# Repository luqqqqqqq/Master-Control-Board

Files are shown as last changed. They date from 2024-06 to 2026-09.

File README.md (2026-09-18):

# Master Control Board v1.0.0

<div align="center">

**面向机器人控制系统的开源 STM32 主控板**<br>
*An open-source STM32 control board for robotics projects*



[快速开始](#快速开始) · [文档导航](#文档导航) · [更新日志](CHANGELOG.md)

</div>

<p align="center">
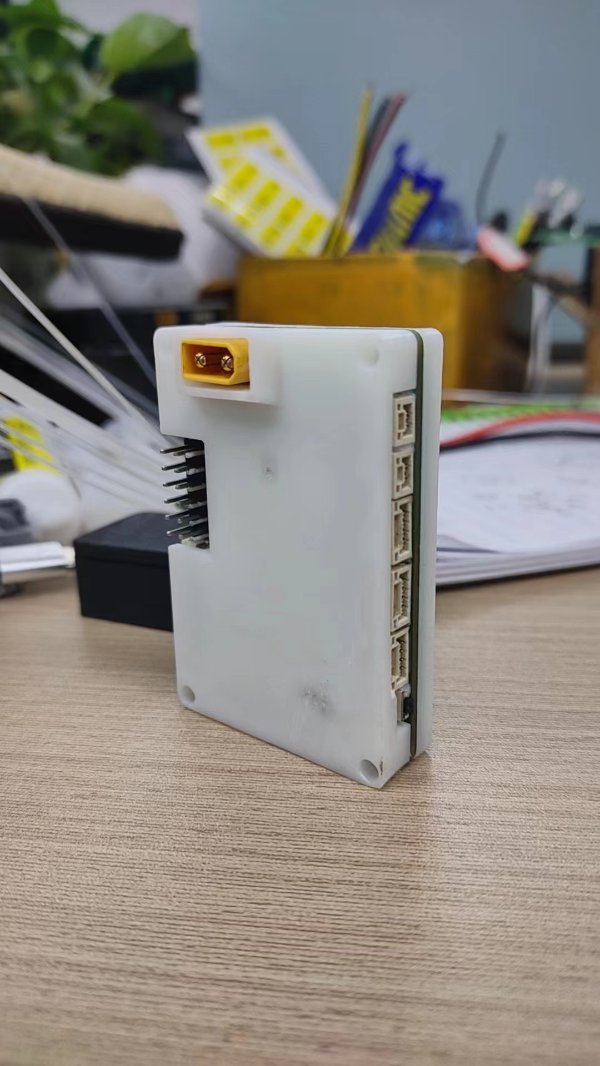
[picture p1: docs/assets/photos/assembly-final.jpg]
Assembled Master Control Board
  
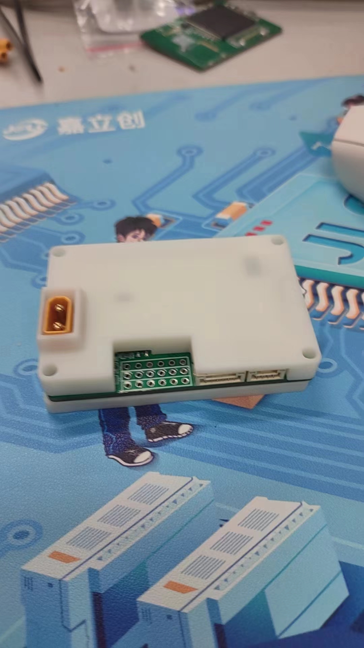
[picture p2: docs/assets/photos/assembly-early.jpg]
Early assembly
  
</p>

## 项目简介

Master Control Board 是一块以 **STM32F407VET6** 为核心、集成 **BMI270 六轴 IMU** 的机器人主控板，定位类似 DJI C Board 的通用控制核心。项目已在 RM 比赛项目中实际使用。本仓库提供 `v1.0.0` 的 PCB、固件、外壳和制造资料。

Master Control Board `v1.0.0` includes hardware design files, firmware, enclosure models and manufacturing files. The board has been used in RM competition projects; formal electrical and environmental test reports are still incomplete.

## 主要特性

| 功能 | 说明 |
| --- | --- |
| MCU | STM32F407VET6，LQFP100，Cortex-M4F |
| IMU | Bosch BMI270，SPI2 接口 |
| 实时系统 | FreeRTOS / CMSIS-RTOS v1 |
| 总线 | CAN1、CAN2（当前 CubeMX 配置为 1 Mbps） |
| 串行接口 | USART1/2/3/6、UART4/5 |
| 其他外设 | SPI1、SPI2、IWDG、RGB 指示灯、激光/外部中断接口 |

## 快速开始

1. 安装 STM32CubeMX、Keil MDK-ARM 和对应的 STM32F4 Device Pack。
2. 用 Keil 打开 [Luq Board.uvprojx](src/firmware/MDK-ARM/Luq%20Board.uvprojx)，选择 `Luq Board` target 后编译。
3. 使用 ST-Link 或 J-Link 烧录生成的固件；仓库也保留了 [v1.0.0 固件镜像](releases/v1.0.0/Luq_Board_v1.0.0.hex)。
4. 制作硬件时，从 [PCB 工程](hardware/pcb/luq_board.eprj) 和 [制造资料](hardware/pcb/manufacturing/) 开始。

完整的环境、编译、烧录与制造入口见 [快速开始](docs/getting-started.md)。制作前请结合板厂能力核对叠层、阻抗和器件封装。

## 目录结构

```text
.
├── src/
│   └── firmware/              # CubeMX、Keil、应用源码与第三方驱动
├── hardware/
│   ├── pcb/                   # PCB 工程、Gerber、BOM 与贴片坐标
│   ├── mechanical/            # 外壳与 3D CAD 文件
│   └── datasheets/            # 芯片参考资料
├── releases/
│   └── v1.0.0/                # 随项目保存的固件镜像
├── tools/
│   └── stm-studio/            # IMU 观察配置
├── docs/
│   ├── README.md              # 文档导航
│   ├── getting-started.md     # 编译、烧录与制造入口
│   ├── development.md         # 外设、工程约定与验证范围
│   ├── firmware-layout.md     # 固件源码与工程入口
│   ├── hardware/              # 制造、装配与 IMU 设计说明
│   └── assets/photos/         # 装配照片
├── README.md
├── CHANGELOG.md
├── VERSION
├── .gitignore
└── LICENSE
```

Keil 中间文件留在工具默认输出目录并由 Git 忽略；`releases/` 只保存明确提供的固件镜像。

## 文档导航

| 文档 | 内容 |
| --- | --- |
| [文档索引](docs/README.md) | 固件、硬件和发布文件的阅读入口 |
| [快速开始](docs/getting-started.md) | 开发环境、编译、烧录与制作硬件 |
| [开发与验证](docs/development.md) | 外设配置、工程约定、STM Studio 与验证范围 |
| [固件目录说明](docs/firmware-layout.md) | CubeMX、Keil 和各源码目录的职责 |
| [制造资料说明](docs/hardware/manufacturing.md) | BOM、贴片坐标与制板前检查 |
| [装配注意事项](docs/hardware/assembly-notes.md) | 外壳、焊点、导热与机械固定 |
| [IMU 设计记录](docs/hardware/imu-layout-notes.md) | 机械应力、温漂和验证建议 |
| [更新日志](CHANGELOG.md) | 版本内容与变更记录 |

## 开发与验证

构建入口为 [Keil 工程](src/firmware/MDK-ARM/Luq%20Board.uvprojx)，配置入口为 [CubeMX 工程](src/firmware/Luq%20Board.ioc)。更完整的维护说明见 [开发与验证](docs/development.md)。

- 已核对工程源文件、包含目录、文档与工具相对引用；目录整理保持固件源码、硬件资产和固件镜像内容不变。
- 本次检查不包含固件编译、烧录或真机测试。
- 项目已在 RM 比赛项目中投入使用；温漂、振动、长期稳定性和完整电气参数测试尚未形成正式报告。
- 目标芯片以 STM32F407VET6 工程配置为准。

## 致谢

感谢 **SZU PR 战队** 提供设备支持和测试条件。

本仓库的 README、文档与目录结构采用作者的 `github-repo-template` 统一模板，通过 Codex 技能维护。

## 许可证

项目顶层采用 [GNU GPL-3.0](LICENSE)。STM32 HAL、CMSIS、FreeRTOS 和 BMI270 API 等第三方代码保留其原始许可证与版权声明；分发时请一并遵守对应目录中的许可文件。

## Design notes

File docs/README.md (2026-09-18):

# 文档导航

[返回项目首页](../README.md)

| 文档 | 内容 |
| --- | --- |
| [快速开始](getting-started.md) | 开发环境、编译、烧录与硬件制作入口 |
| [开发与验证](development.md) | 外设配置、代码约定、STM Studio 与验证范围 |
| [固件目录说明](firmware-layout.md) | CubeMX、Keil 与各源码目录的职责 |
| [制造资料说明](hardware/manufacturing.md) | 制造文件及下单前检查 |
| [装配注意事项](hardware/assembly-notes.md) | 外壳、导热、焊点与机械固定 |
| [IMU 设计记录](hardware/imu-layout-notes.md) | 应力、温漂与验证建议 |
| [固件镜像](../releases/v1.0.0/README.md) | 随项目保存的 v1.0.0 HEX 文件 |
| [更新日志](../CHANGELOG.md) | 版本内容与变更记录 |

初次使用从“快速开始”阅读；修改固件前阅读“开发与验证”，制作硬件前核对制造与装配说明。芯片参考资料见 [hardware/datasheets](../hardware/datasheets/)。

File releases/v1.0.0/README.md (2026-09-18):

# Master Control Board v1.0.0 固件

[返回项目首页](../../README.md) · [快速开始](../../docs/getting-started.md)

本目录保留随项目提供的 [Luq_Board_v1.0.0.hex](Luq_Board_v1.0.0.hex)。目录整理未重新编译或修改该镜像。

目标工程为 STM32F407VET6。烧录前确认实际板卡、连接方式和固件需求；修改源码后请从 [Keil 工程](../../src/firmware/MDK-ARM/Luq%20Board.uvprojx) 重新构建，再验证生成的固件。

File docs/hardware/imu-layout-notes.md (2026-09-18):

# BMI270 区域设计记录

BMI270 的零偏和温漂会受到 PCB 应变、外部振动和温度梯度影响。本文件记录当前版本的设计取舍，属于工程笔记，不能替代实测数据。

## 机械应力

- 在陀螺仪周围保留足够的开槽和净空，减少板弯和外壳装配力传递到器件。
- 外壳固定可以提高整体抗冲击能力，但螺丝和卡扣不能直接给 PCB 施加过大预紧力。
- PCB 加厚能提高刚性，同时会增加重量、成本和热阻，应通过振动与温漂测试决定是否采用。

## 热设计

- 可使用柔性导热垫或低应力固化导热材料帮助均温，但必须控制厚度和固化收缩。
- 导热材料不应挤压 BMI270，也不应遮挡需要保持开口的结构区域。
- 热路径应连接到连续铜区或外壳散热结构；单纯增加材料厚度不能替代温度测试。

## 验证建议

装配完成后，建议分别记录静置、升温、风扇扰动和振动条件下的零偏变化，并把测试结果与机械方案、导热材料批次一起归档。

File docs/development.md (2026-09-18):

# 开发与验证

[返回项目首页](../README.md) · [文档导航](README.md)

本文记录 `v1.0.0` 固件的 CubeMX/Keil 配置要点。工程目标以 `Luq Board.ioc` 和 Keil 工程中的 `STM32F407VETx` 配置为准；下文源码路径均相对于 [`src/firmware/`](../src/firmware/)。

## 快速构建

1. 使用 STM32CubeMX 打开 `Luq Board.ioc`，芯片选择 STM32F407VET6、LQFP100。
2. 使用 Keil MDK-ARM 打开 `MDK-ARM/Luq Board.uvprojx`。
3. 安装对应版本的 STM32F4xx Device Pack，选择 `Luq Board` target 后编译。
4. 使用 ST-Link 或 J-Link 烧录生成的 `.hex` 文件。

## 外设概览

- **CAN1、CAN2**：CubeMX 当前配置为 1 Mbps，启用自动离线管理和自动唤醒。
- **USART1/2/3、UART4/5、USART6**：串口接收使用 DMA/中断组合，具体引脚以 `.ioc` 为准。
- **SPI1、SPI2**：SPI2 连接 BMI270，片选由 GPIO 控制。
- **FreeRTOS**：任务入口在 `Task/Src/user_task.c`，回调集中在 `Task/Src/user_handler.c`。
- **IWDG**：用于基础运行时看门狗保护。

## 工程约定

- `Core/` 保存 CubeMX 生成的初始化、中断和 HAL glue code。
- `Peripherals/` 提供 CAN、UART、SPI、TIM、GPIO 等项目驱动封装。
- `BMI270/` 保留 Bosch BMI270 Sensor API 及其适配代码。
- 重生成 CubeMX 工程时，保留用户代码区，并检查 Keil 工程中的 include path 和 source group。
- 任务逻辑优先放入 `Task/`，设备初始化放在 `Peripherals/Src/dev_drv.c`，对应头文件位于 `Peripherals/Inc/dev_drv.h`。

## 关键配置

### 时钟与系统

- 使用外部高速晶振，系统时钟按 STM32F407VET6 的最高允许频率配置。
- HAL 时基使用 TIM2，FreeRTOS 使用 SysTick。
- 开启 FPU、IWDG 和 CMSIS-RTOS v1；FreeRTOS 堆大小在 CubeMX 工程中设置。

### 接口分配

最终引脚、DMA stream、NVIC 优先级和 CAN 时序均以 `Luq Board.ioc` 为准。修改 CubeMX 配置后，需要重新检查 Keil 工程的用户文件分组和 include path。

### 项目驱动

- `uart_drv.*`：串口 DMA/空闲线接收封装。
- `can_drv.*`：CAN 收发和接收回调封装。
- `tim_drv.*`：定时器功能扩展点。
- `gpio_drv.*`：LED、激光和外部中断相关 GPIO 宏与操作。
- `bmi_drv.*`：BMI270 初始化和数据读取适配。

## STM Studio 观察 IMU

使用 STM Studio 打开 [st-studio-imu.tsp](../tools/stm-studio/st-studio-imu.tsp)，它引用同目录的 [st-studio-imu.tsc](../tools/stm-studio/st-studio-imu.tsc)。配置指向本地编译生成的 `src/firmware/MDK-ARM/Luq Board/Luq Board.axf`，用于查看 `test.acc_*`、`test.gyr_*` 和 `test.temp`。

使用前先编译对应固件，并在 STM Studio 中确认或重新导入当前 AXF 的变量地址；配置中保存的历史地址不能代替当前构建的符号信息。日志写入 `tools/stm-studio/st-studio-imu.log`，已加入忽略规则。

## 验证范围

- 已核对 Keil 工程的 54 个源文件引用和 12 个包含目录条目，以及 STM Studio 配置的相对路径。
- 目录整理保持固件源码、工程内部布局、硬件资产、第三方内容与 HEX 镜像不变。
- 静态检查不包含 Keil 编译、烧录、IMU 实测或电气测试。
- 项目有 RM 比赛应用经历，但温漂、振动、长期稳定性与完整电气参数报告仍待完善。

修改 CubeMX 配置或固件功能后，应重新编译并验证实际板卡行为；对外发布时保持 [VERSION](../VERSION)、根 README 和 [更新日志](../CHANGELOG.md) 一致，并保留第三方许可证。

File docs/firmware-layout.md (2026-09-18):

# 固件目录说明

[返回项目首页](../README.md) · [文档导航](README.md) · [快速开始](getting-started.md)

STM32F407VET6 固件位于 [`src/firmware/`](../src/firmware/)。CubeMX、Keil 和各源码目录之间的相对布局保持一致。

## 工程入口

| 文件 | 用途 |
| --- | --- |
| [Luq Board.ioc](../src/firmware/Luq%20Board.ioc) | CubeMX 芯片、时钟、外设与中间件配置 |
| [Luq Board.uvprojx](../src/firmware/MDK-ARM/Luq%20Board.uvprojx) | Keil MDK-ARM 工程，target 为 `Luq Board` |
| [v1.0.0 固件镜像](../releases/v1.0.0/Luq_Board_v1.0.0.hex) | 随项目保存的可烧录 HEX 文件 |

## 源码职责

| 目录 | 内容 |
| --- | --- |
| `Core/` | CubeMX 生成的初始化、中断与 HAL 适配 |
| `Drivers/` | STM32 HAL 与 CMSIS 依赖 |
| `Middlewares/` | FreeRTOS 及 CMSIS-RTOS 接口 |
| `BMI270/` | Bosch BMI270 API |
| `Peripherals/` | CAN、UART、SPI、TIM、GPIO 和 IMU 的项目封装 |
| `Task/` | 用户任务与回调 |
| `MDK-ARM/` | Keil 工程、启动代码与本地构建输出 |

Keil 的本地输出目录为 `src/firmware/MDK-ARM/Luq Board/`，其中的 `.axf`、`.hex` 和中间文件默认忽略。对外提供的固件镜像统一位于 `releases/v1.0.0/`。

重生成 CubeMX 工程或调整文件分组后，应重新核对用户代码区、源文件引用和包含目录。外设配置与维护约定见 [开发与验证](development.md)。

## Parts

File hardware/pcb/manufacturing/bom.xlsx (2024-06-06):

No. | Quantity | Comment | Designator | Footprint | Value | Manufacturer Part | Manufacturer | Supplier Part | Supplier
1 | 2 | 12pF | C1,C2 | C0603 | 12pF | CL10C120JB8NNNC | SAMSUNG(三星) | C38523 | LCSC
2 | 13 | 100nF | C3,C4,C7,C8,C11,C13,C14,C17,C18,C19,C20,C21,C22 | C0603 | 100nF | CC0603KRX7R9BB104 | YAGEO(国巨) | C14663 | LCSC
3 | 3 | 47uF | C5,C6,C12 | C1206 | 47uF | GRM31CR61E476ME44L | muRata(村田) | C403725 | LCSC
4 | 2 | 3.3nF | C9,C16 | C0603 | 3.3nF | CC0603KRX7R9BB332 | YAGEO(国巨) | C107088 | LCSC
5 | 4 | 10uF | C10,C15,C23,C24 | C0603 | 10uF | CL10A106MA8NRNC | SAMSUNG(三星) | C96446 | LCSC
6 | 1 | L125WVS-02PW | CN1 | CONN-SMD_2P-P1.25_DELON_L125WVS-02PW |  | L125WVS-02PW | DEALON(德艺隆) | C2998790 | LCSC
7 | 1 | XT30U-M | CN2 | CONN-TH_XT30U-M |  | XT30U-M | AMASS(艾迈斯) | C99101 | LCSC
8 | 2 | GH1.25-2PWBPZ | CN3,CN4 | CONN-SMD_GH1.25-2PWBPZ |  | GH1.25-2PWBPZ | BOOMELE(博穆精密) | C2829251 | LCSC
9 | 3 | MF254V-11-06-0743 | H1,H2,H3 | HDR-TH_6P-P2.54-V-F_MF254V-11-06-0743 |  | MF254V-11-06-0743 | XFCN(兴飞) | C962325 | LCSC
10 | 2 | 6.8uH | L1,L2 | IND-SMD_L5.4-W5.2_FXL0530 | 6.8uH | FXL0530-6R8-M | cjiang(长江微电) | C177249 | LCSC
11 | 3 | NCD0603R1 | LED1,LED2,LED3 | LED0603-RD_RED |  | NCD0603R1 | 国星光电 | C84263 | LCSC
12 | 1 | NCD0603G1 | LED4 | LED0603-RD |  | NCD0603G1 | 国星光电 | C84267 | LCSC
13 | 2 | SS8050 | Q1,Q2 | S8050_SOT-23 |  | SS8050 | CJ(江苏长电/长晶) | C2150 | LCSC
14 | 1 | BSC0702LS | Q3 | PG-TDSON-8_L5.0-W6.0-P1.27-BL-EP |  | BSC0702LS | Infineon(英飞凌) | C501503 | LCSC
15 | 14 | 10kΩ | R1,R2,R6,R7,R8,R10,R14,R15,R16,R17,R18,R19,R20,R24 | R0603 | 10kΩ | 0603WAF1002T5E | UNI-ROYAL(厚声) | C25804 | LCSC
16 | 3 | 50kΩ | R3,R11,R23 | R0603 | 50kΩ | AR03BTC5002A | Viking(光颉) | C304067 | LCSC
17 | 2 | 200kΩ | R4,R12 | R0603 | 200kΩ | 0603WAF2003T5E | UNI-ROYAL(厚声) | C25811 | LCSC
18 | 2 | 33kΩ | R5,R13 | R0603 | 33kΩ | 0603WAF3302T5E | UNI-ROYAL(厚声) | C4216 | LCSC
19 | 1 | 100mΩ | R9 | R1206 | 100mΩ | 1206W4F100LT5E | UNI-ROYAL(厚声) | C25334 | LCSC
20 | 2 | 120Ω | R21,R22 | R0603 | 120Ω | 0603WAF1200T5E | UNI-ROYAL(厚声) | C22787 | LCSC
21 | 1 | TS24CA | SW1 | SW-SMD_TS24CA |  | TS24CA | SHOU HAN(首韩) | C393942 | LCSC
22 | 1 | STM32F407VGT6 | U1 | LQFP-100_L14.0-W14.0-P0.50-LS16.0-BL |  | STM32F407VGT6 | ST(意法半导体) | C12345 | LCSC
23 | 6 | GH1.25-4PWBPZ | U2,U3,U5,U6,U8,U9 | CONN-SMD_GH1.25-4PWBPZ |  | GH1.25-4PWBPZ | BOOMELE(博穆精密) | C2829253 | LCSC
24 | 2 | SCT2450QSTER | U4,U7 | ESOP-8_L4.9-W3.9-P1.27-LS6.0-BL-EP |  | SCT2450QSTER | SCT(芯洲科技) | C2929524 | LCSC
25 | 1 | BMI270 | U10 | LGA-14_L3.0-W2.5-P0.50-BR |  | BMI270 | Bosch(博世) | C2836813 | LCSC
26 | 1 | XC6220B331MR | U11 | SOT-23-5_L2.9-W1.6-P0.95-LS2.8-BR |  | XC6220B331MR | TECH PUBLIC(台舟) | C3040644 | LCSC
27 | 1 | HC-GH-6PWT | U12 | CONN-SMD_6P-P1.25_HCTL_HC-GH-6PWT |  | HC-GH-6PWT | HCTL(华灿天禄) | C3011948 | LCSC
28 | 2 | MAX3051EKA+T | U13,U15 | SOT-23-8_L3.0-W1.7-P0.65-LS2.8-TL |  | MAX3051EKA+T | ADI(亚德诺) | C112005 | LCSC
29 | 1 | SMF22A | U14 | SOD-123FL_L2.8-W1.9-LS3.7-RD |  | SMF22A | GOODWORK(固得沃克) | C2943862 | LCSC
30 | 1 | SMF12A | U16 | SOD-123FL_L2.7-W1.8-LS3.7-RD |  | SMF12A | GOODWORK(固得沃克) | C2943870 | LCSC
31 | 1 | 25MHz | X1 | OSC-SMD_4P-L3.2-W2.5-BL | 25MHz | X322525MOB4SI | YXC(扬兴晶振) | C9006 | LCSC

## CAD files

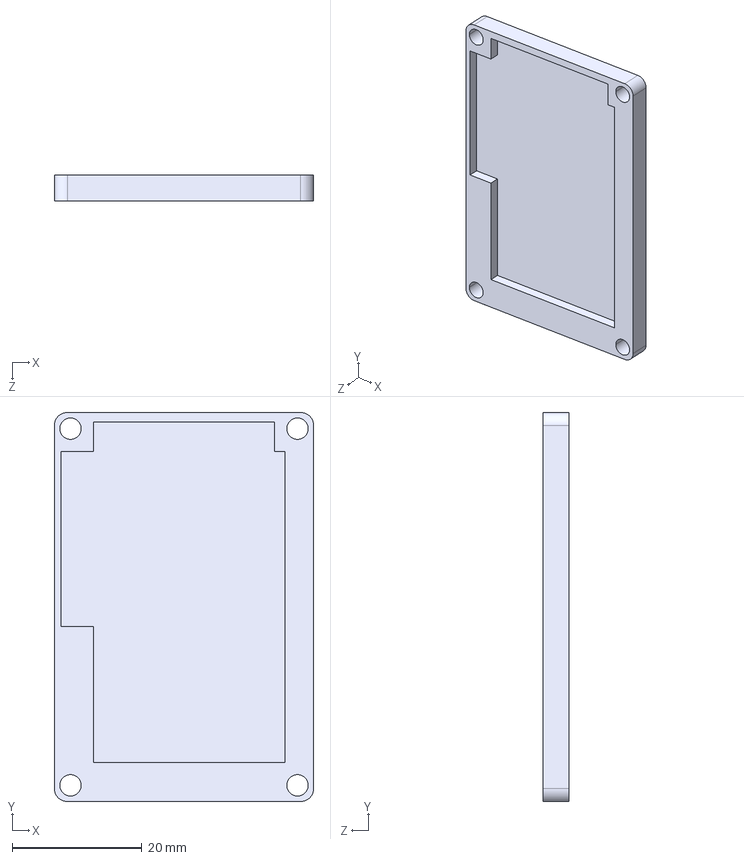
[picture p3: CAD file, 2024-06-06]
hardware/mechanical/case-straight-bottom.step
40.0 x 60.0 x 4.00 mm

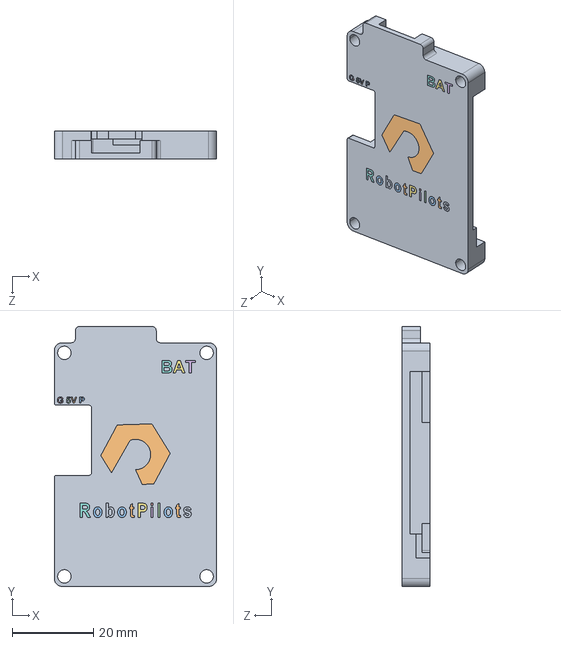
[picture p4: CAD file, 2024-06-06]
hardware/mechanical/case-angle-top.step
40.0 x 64.0 x 7.00 mm

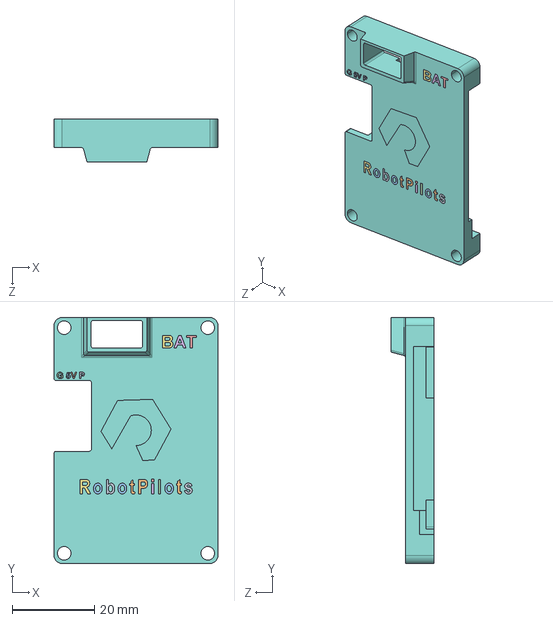
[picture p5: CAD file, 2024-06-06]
hardware/mechanical/case-straight-top.step
40.0 x 60.0 x 10.5 mm

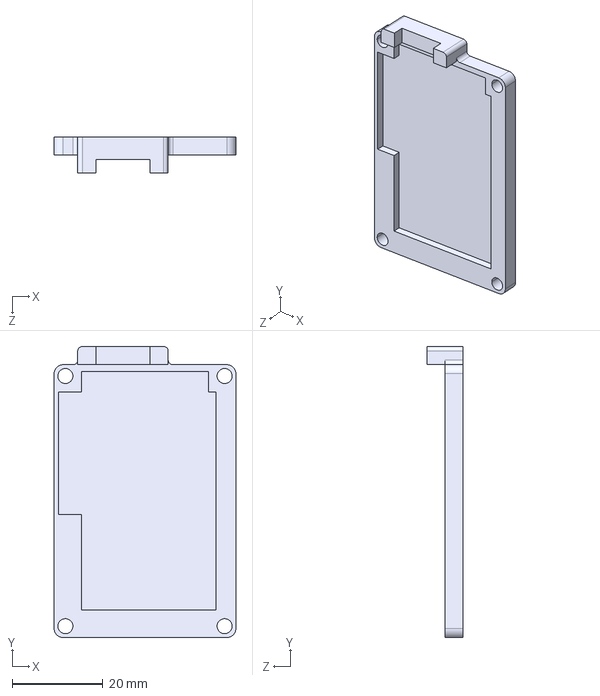
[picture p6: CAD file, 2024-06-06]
hardware/mechanical/case-angle-bottom.step
40.0 x 64.0 x 8.00 mm

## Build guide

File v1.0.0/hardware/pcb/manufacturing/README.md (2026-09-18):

# PCB 制造资料

本目录包含生产所需的 BOM、贴片坐标和制造压缩包：

- `gerber-and-fabrication.zip`：Gerber/制板文件
- `bom.xlsx`：物料清单
- `pick-and-place.xlsx`：贴片坐标

## 下单前检查

1. 向板厂确认叠层、板厚、阻抗和铜厚。不同 PP 片材会改变最终厚度和阻抗，不能只按文件名下单。
2. 当前设计曾按 JLC 常见的 7628/3313 方案评估；具体选型请以板厂可提供的材料和阻抗计算为准。
3. 焊接后检查 RGB LED 方向：靠近按键的一侧为 R，左侧为 G，最右侧为 B。
4. 生产前重新核对封装、替代料和 BOM 版本，并在制造记录中保存板厂回传的叠层参数。

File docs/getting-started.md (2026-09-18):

# 快速开始

[返回项目首页](../README.md) · [文档导航](README.md)

Master Control Board `v1.0.0` 面向 STM32F407VET6。使用前请确认实际板卡和工程的芯片、供电与接口配置相符。

## 准备环境

| 工具 | 用途 |
| --- | --- |
| STM32CubeMX | 查看或修改芯片、时钟、引脚和中间件配置 |
| Keil MDK-ARM | 编译工程并进行下载、调试 |
| ARM Compiler | 工程记录为 5.06 update 7 (build 960)，使用 ARMCC |
| STM32F4 Device Pack | 工程记录为 Keil.STM32F4xx_DFP 2.11.0 |
| ST-Link 或 J-Link | 连接板卡并烧录、调试 |
| STM Studio（可选） | 通过项目配置观察 IMU 变量 |

工程入口为 [Luq Board.uvprojx](../src/firmware/MDK-ARM/Luq%20Board.uvprojx)，CubeMX 配置为 [Luq Board.ioc](../src/firmware/Luq%20Board.ioc)。表中编译器与 Device Pack 版本来自工程文件，不代表最低兼容版本或本次已完成构建验证。若当前 MDK 默认使用 Arm Compiler 6 / armclang，应先配置工程所需的 ARMCC，或另行完成迁移和验证。仓库没有附带这些开发工具。

## 编译固件

1. 用 Keil 打开 `src/firmware/MDK-ARM/Luq Board.uvprojx`。
2. 确认目标为 `Luq Board`，器件为 STM32F407VETx，并安装缺少的 STM32F4 Device Pack。
3. 执行 Build，确认没有编译或链接错误。
4. 在 `src/firmware/MDK-ARM/Luq Board/` 查看本次生成的 `.hex` 和 `.axf`。

通常无需先重新生成 CubeMX 代码。需要修改外设配置时，保留用户代码区并检查 Keil 文件分组与包含路径，详情见 [开发与验证](development.md)。

## 烧录与观察

使用 ST-Link 或 J-Link 连接实际板卡，按照所用下载工具设置目标芯片与连接方式后，烧录本次构建的 HEX。仓库另保留 [Luq_Board_v1.0.0.hex](../releases/v1.0.0/Luq_Board_v1.0.0.hex) 作为随项目提供的镜像，目录整理没有重新编译该文件。

需要观察 IMU 时，打开 [STM Studio 项目](../tools/stm-studio/st-studio-imu.tsp)，使用与已烧录固件对应的 AXF 更新变量信息。具体相对路径和日志位置见 [开发与验证](development.md#stm-studio-观察-imu)。

## 制作硬件

| 资料 | 入口 |
| --- | --- |
| PCB 工程 | [luq_board.eprj](../hardware/pcb/luq_board.eprj) |
| Gerber、BOM 与贴片坐标 | [制造文件目录](../hardware/pcb/manufacturing/) |
| 外壳与 3D CAD | [机械文件目录](../hardware/mechanical/) |
| 芯片参考资料 | [datasheets](../hardware/datasheets/) |
| 装配照片 | [photos](assets/photos/) |

下单前结合板厂能力核对叠层、板厚、阻抗、器件封装与替代料。制造细节见 [制造资料说明](hardware/manufacturing.md)，组装时参考 [装配注意事项](hardware/assembly-notes.md) 和 [IMU 设计记录](hardware/imu-layout-notes.md)。

## 下一步

源码职责见 [固件目录说明](firmware-layout.md)。实际使用前应验证所需接口、控制逻辑和板卡行为；现有静态路径检查不代替编译、烧录和硬件测试。

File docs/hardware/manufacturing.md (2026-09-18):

# PCB 制造资料

生产资料位于 [`hardware/pcb/manufacturing/`](../../hardware/pcb/manufacturing/)，包含 BOM、贴片坐标和制造压缩包：

- [gerber-and-fabrication.zip](../../hardware/pcb/manufacturing/gerber-and-fabrication.zip)：Gerber/制板文件
- [bom.xlsx](../../hardware/pcb/manufacturing/bom.xlsx)：物料清单
- [pick-and-place.xlsx](../../hardware/pcb/manufacturing/pick-and-place.xlsx)：贴片坐标

## 下单前检查

1. 向板厂确认叠层、板厚、阻抗和铜厚。不同 PP 片材会改变最终厚度和阻抗，不能只按文件名下单。
2. 当前设计曾按 JLC 常见的 7628/3313 方案评估；具体选型请以板厂可提供的材料和阻抗计算为准。
3. 焊接后检查 RGB LED 方向：靠近按键的一侧为 R，左侧为 G，最右侧为 B。
4. 生产前重新核对封装、替代料和 BOM 版本，并在制造记录中保存板厂回传的叠层参数。

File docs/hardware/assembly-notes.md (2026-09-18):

# 外壳与装配注意事项

- 背部焊点即使不使用，也要确认不会与外壳或其他导体短路。
- 焊接完成后，按器件和返修需求选择合适的三防胶覆盖焊点。
- BMI270 区域可使用薄层固化硅脂均温；避免过厚或形成明显机械预紧。
- MCU 可按散热需求涂覆导热材料，施工时不要污染连接器、按键和光学件。
- 使用导光柱时，先确认位置，再用热熔胶或更可靠的结构方式固定。
- 拧紧螺丝时交叉、分阶段施力，避免 PCB 局部弯曲。
- 白色光敏树脂会削弱指示灯亮度，可改用透明树脂、开孔或导光柱；更换限流电阻会改变功耗。
- 当前外壳粘接方案的外观和可靠性仍有优化空间，建议在量产前制作样件验证。

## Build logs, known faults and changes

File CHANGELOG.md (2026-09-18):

# 更新日志

## [v1.0.0]

- 提供搭载 STM32F407VET6 和 BMI270 的主控板设计。
- 包含 CAN1/CAN2、USART/UART、SPI 与 FreeRTOS 固件工程。
- 提供 PCB 工程、制造资料、外壳、芯片资料和装配照片。
- 提供 CubeMX / Keil 工程、预编译固件、开发说明与装配记录。
- 固件、硬件、发布文件、工具配置和文档按用途分别组织，版本号记录于 `VERSION`。
- 项目采用 GPL-3.0，第三方组件保留各自原始许可证。

[v1.0.0]: https://github.com/luqqqqqqq/Master-Control-Board/tree/v1.0.0

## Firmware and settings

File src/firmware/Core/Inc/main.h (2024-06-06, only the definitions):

#define SPI1_CS_Pin GPIO_PIN_4
#define SPI1_CS_GPIO_Port GPIOA
#define LED_R_Pin GPIO_PIN_9
#define LED_R_GPIO_Port GPIOE
#define LED_G_Pin GPIO_PIN_10
#define LED_G_GPIO_Port GPIOE
#define LED_B_Pin GPIO_PIN_11
#define LED_B_GPIO_Port GPIOE
#define SPI2_CS_Pin GPIO_PIN_12
#define SPI2_CS_GPIO_Port GPIOB
#define INT1_Pin GPIO_PIN_8
#define INT1_GPIO_Port GPIOD
#define INT1_EXTI_IRQn EXTI9_5_IRQn
#define INT2_Pin GPIO_PIN_9
#define INT2_GPIO_Port GPIOD
#define INT2_EXTI_IRQn EXTI9_5_IRQn
#define LASER_Pin GPIO_PIN_9
#define LASER_GPIO_Port GPIOC

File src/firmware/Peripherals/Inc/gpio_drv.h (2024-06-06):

#ifndef __GPIO_DRV_H
#define __GPIO_DRV_H

/* Includes ------------------------------------------------------------------*/
#include "stm32f4xx_hal.h"
#include "gpio.h"

//you can define written func in here 
//note!!!!! C99 invalid
#define LED_R_ON LED_R(GPIO_PIN_SET);
#define LED_G_ON LED_G(GPIO_PIN_SET);
#define LED_B_ON LED_B(GPIO_PIN_SET);
#define LED_R_OFF LED_R(GPIO_PIN_RESET);
#define LED_G_OFF LED_G(GPIO_PIN_RESET);
#define LED_B_OFF LED_B(GPIO_PIN_RESET);
#define SPI1_CS_ON SPI1_CS(GPIO_PIN_RESET);
#define SPI2_CS_ON SPI2_CS(GPIO_PIN_RESET);
#define SPI1_CS_OFF SPI1_CS(GPIO_PIN_SET);
#define SPI2_CS_OFF SPI2_CS(GPIO_PIN_SET);


void LED_R(GPIO_PinState PinState);
void LED_G(GPIO_PinState PinState);
void LED_B(GPIO_PinState PinState);
void SPI1_CS(GPIO_PinState PinState);
void SPI2_CS(GPIO_PinState PinState);

//GPIO it handle need to rewrite
__weak void HAL_GPIO_EXTI_Callback(uint16_t GPIO_Pin);

#endif

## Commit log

2024-06-06 STM32f407 Ver2.0 finished
    [PickAndPlace.xlsx, bom.xlsx, 弯插上壳.STEP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]
2024-06-14 wait for test
    [弯插上壳.STEP, 弯插下壳.STEP, 直插上壳.STEP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]
2026-09-18 Reorganize stable design as v1.0.0
    Remove the abandoned Version 1 tree and generated Keil artifacts, regroup hardware and firmware assets, and publish a complete bilingual project README with build and manufacturing guidance.
    [bom.xlsx, case-angle-bottom.step, case-angle-top.step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]
2026-09-18 Switch project license to GPL-3.0
2026-09-18 docs: organize board assets and align repository presentation
    [bom.xlsx, case-angle-bottom.step, case-angle-top.step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]

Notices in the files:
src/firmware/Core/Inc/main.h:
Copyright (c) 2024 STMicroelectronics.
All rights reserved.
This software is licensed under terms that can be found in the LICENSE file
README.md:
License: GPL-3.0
